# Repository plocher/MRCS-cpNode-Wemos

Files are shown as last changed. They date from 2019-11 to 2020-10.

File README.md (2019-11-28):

# MRCS-cpNode-Wemos
## License: Creative Commons Attribution-NonCommercial-ShareAlike

cpNode (2.7" Tyco Rail) processor for MRCS CMRI applications

Designed for MRCS as an outgrowth of the [Core-Wemos](/pages/Core-Wemos.html) project, this version includes
CMRI-Net interface circuitry (V4) or interconnect to an external driver (V5 - [CMRI-Bus-Interface](/pages/CMRI-Bus-Interface.html)).

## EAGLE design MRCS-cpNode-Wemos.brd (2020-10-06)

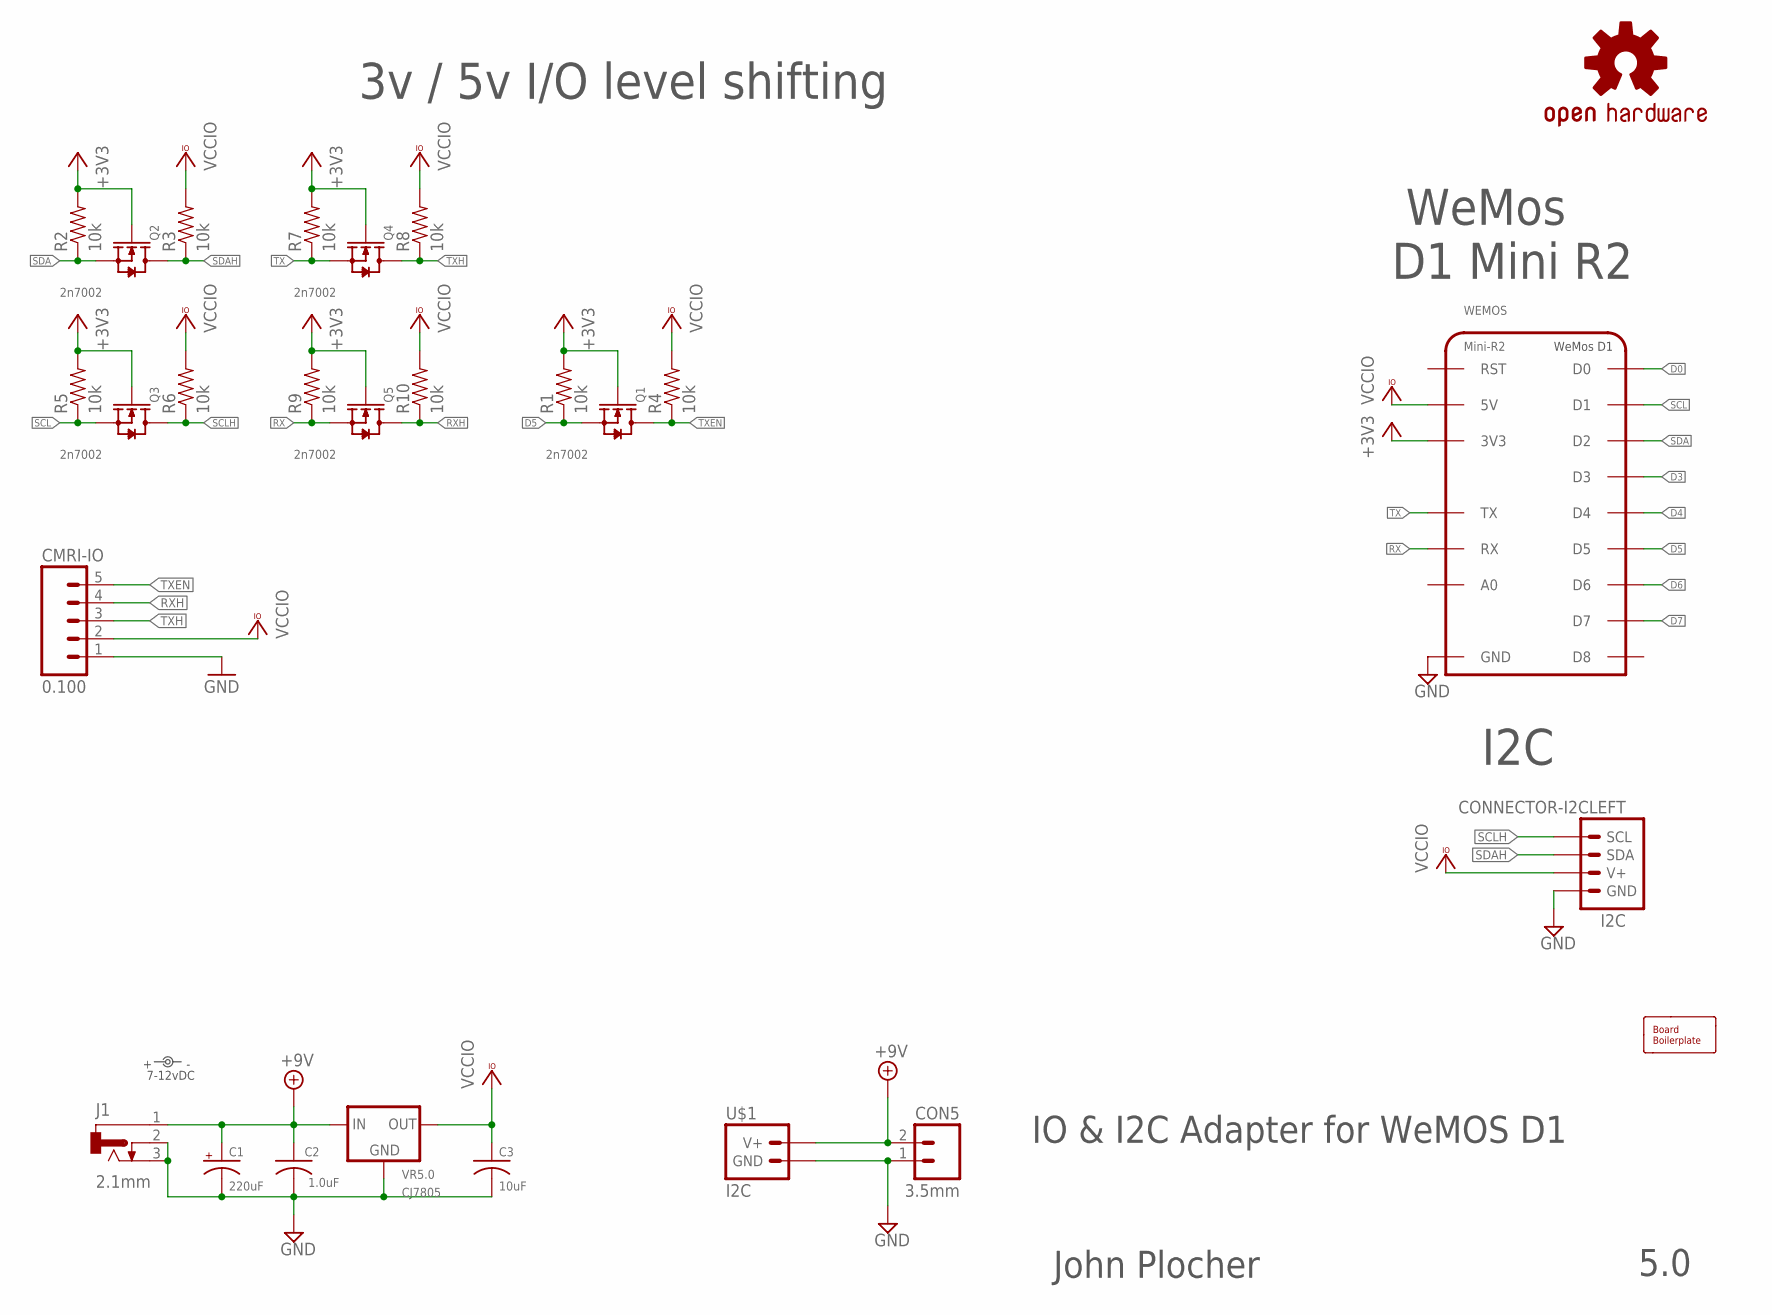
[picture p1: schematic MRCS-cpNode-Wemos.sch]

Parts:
BOARD: BOARD; BOARD-DINRAIL-2.7IN-8CM
C1: 220uF; 0810-CAP
C2: 1.0uF; 0603-CAP
C3: 10uF; 0603-CAP
CMRI-IO: 0.100; 1X05_LOCK_LONGPADS
CON5: 3.5mm; SCREWTERMINAL-3.5MM-2_LOCK
I2C: CONNECTOR-I2CLEFT; I2C-L
J1: 2.1mm; DCJ0202
LABEL1: 7-12vDC; PWR_LABEL
OSHW1: OSHW; OSHW-LOGO-L
Q1, Q2, Q3, Q4, Q5: 2n7002; SOT23
R1: 10k; 0805-RES
R2, R3, R4, R5, R6, R7, R8, R9, R10: 10k; 0603-RES
U$1: I2C; POWER-R2
VR5.0: CJ7805; TO-252
WEMOS: Mini-R2; WEMOS-D1

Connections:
+3V3: Q1.1 (G), Q2.1 (G), Q3.1 (G), Q4.1 (G), Q5.1 (G), R1.2, R2.2, R5.2, R7.2, R9.2, WEMOS.3V3
+9V: C1.+, C2.1, CON5.2 (B), J1.1, U$1.V+, U$1.V+@1 (V+), U$1.V+@2 (V+), U$1.V+@3 (V+), VR5.0.1 (IN)
D0: WEMOS.D0
D3: WEMOS.D3
D4: WEMOS.D4
D5: Q1.2 (S), R1.1, WEMOS.D5
D6: WEMOS.D6
D7: WEMOS.D7
GND: C1.-, C2.2, C3.2, CMRI-IO.1, CON5.1 (A), I2C.GND, I2C.GND@1 (GND), J1.2, J1.3, U$1.GND, U$1.GND@1 (GND), U$1.GND@2 (GND), U$1.GND@3 (GND), VR5.0.2 (GND), WEMOS.GND
RX: Q5.2 (S), R9.1, WEMOS.RX
RXH: CMRI-IO.4, Q5.3 (D), R10.1
SCL: Q3.2 (S), R5.1, WEMOS.D1
SCLH: I2C.SCL, I2C.SCL@1 (SCL), Q3.3 (D), R6.1
SDA: Q2.2 (S), R2.1, WEMOS.D2
SDAH: I2C.SDA, I2C.SDA@1 (SDA), Q2.3 (D), R3.1
TX: Q4.2 (S), R7.1, WEMOS.TX
TXEN: CMRI-IO.5, Q1.3 (D), R4.1
TXH: CMRI-IO.3, Q4.3 (D), R8.1
VCCIO: C3.1, CMRI-IO.2, I2C.V+, I2C.V+@1 (V+), R3.2, R4.2, R6.2, R8.2, R10.2, VR5.0.3 (OUT), WEMOS.5V

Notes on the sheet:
IO & I2C Adapter for WeMOS D1
John Plocher
5.0
I2C
WeMos D1 Mini R2
3v / 5v I/O level shifting

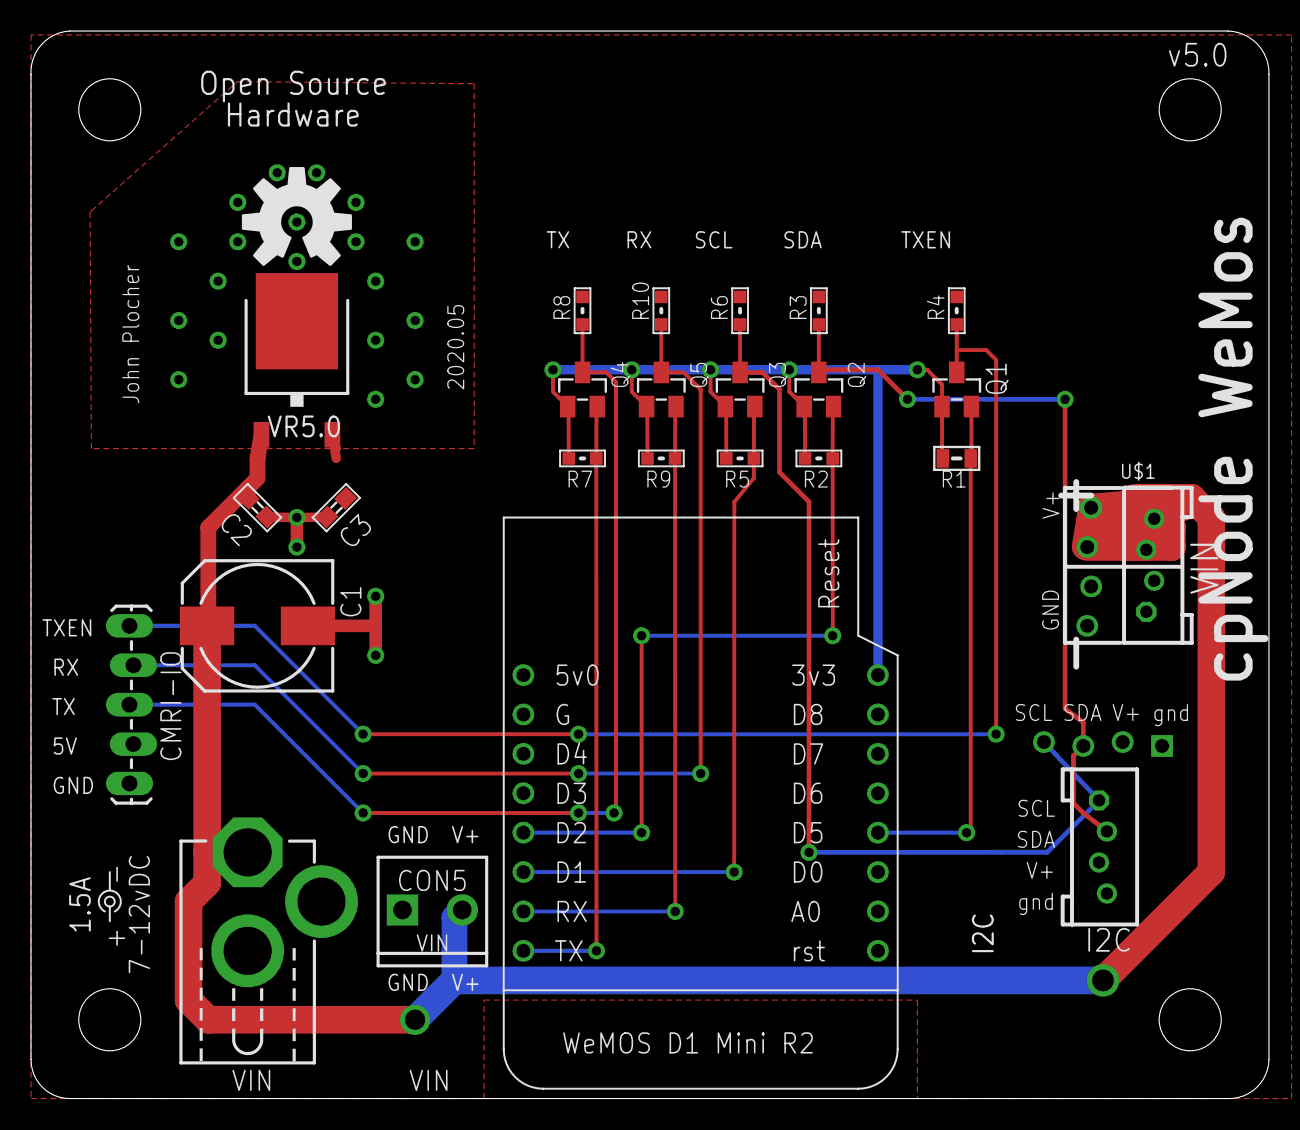
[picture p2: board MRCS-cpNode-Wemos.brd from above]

Board: 2 copper layers, 79.8 x 68.8 mm, 28 parts (0 on the bottom side), 14 nets.

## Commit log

2020-05-05 cleanup, DRC, ERC
    [MRCS-cpNode-Wemos.brd, MRCS-cpNode-Wemos.sch]
2020-10-05 added missing values
    [MRCS-cpNode-Wemos.brd, MRCS-cpNode-Wemos.sch]
2020-10-06 normalized values
    [MRCS-cpNode-Wemos.brd, MRCS-cpNode-Wemos.sch]
